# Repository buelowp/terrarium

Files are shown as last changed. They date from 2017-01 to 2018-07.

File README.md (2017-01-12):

# Terrarium Control

The idea here is to provide a mechanism for controlling a small terrarium for plants that like humidity and warm. I'm doing this to control lights for a small planting of venus flytraps in my office. It provides a small bit of fun engineering for a simple mechanism.

## What's needed

1. WeMos D1 Mini (microcontroller)
1. 1.3 in OLED (Adafruit product id 938)
1. DHT22 (Temp and Humidity)
1. Soil Moisture Sensor (Sparkfun SEN-13322)
1. NeoPixel strip (Adafruit product id 1426)
1. UV LED 400nm (Sparkfun COM-08662)
1. 3v3 voltage regulator (Sparkfun COM-00526)
1. Power Supply (Sparkfun TOL-12889)
1. 1 x 470ohm 1/4 watt resistor
1. 2 x 1kohm 1/4 watt resistor
1. 1 x 10kohm 1/4 watt resistor
1. 2 x 2N3904 NPN Transistor (Sparkfun)
1. 1 x 100uf capacitor

## How to build it

The design is based on building a plastic terrarium from PVC and 3d printed parts. The 3d parts are a base and cap. There are 2 caps included, one that fits the OSH Park PCB, and one that would work with a standard breadboard solution. The 3d printed files include the .skp files if you want to make changes. The base contains the peat/soil, and the cap contains the electronics. The visible portion is 4 cut Plexi sheets (1/8 in) to fit the base and cap. These are fashioned into a box onto which the base and cap fit.

More to come.

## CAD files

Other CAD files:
Mech/base.skp
Mech/cap.skp

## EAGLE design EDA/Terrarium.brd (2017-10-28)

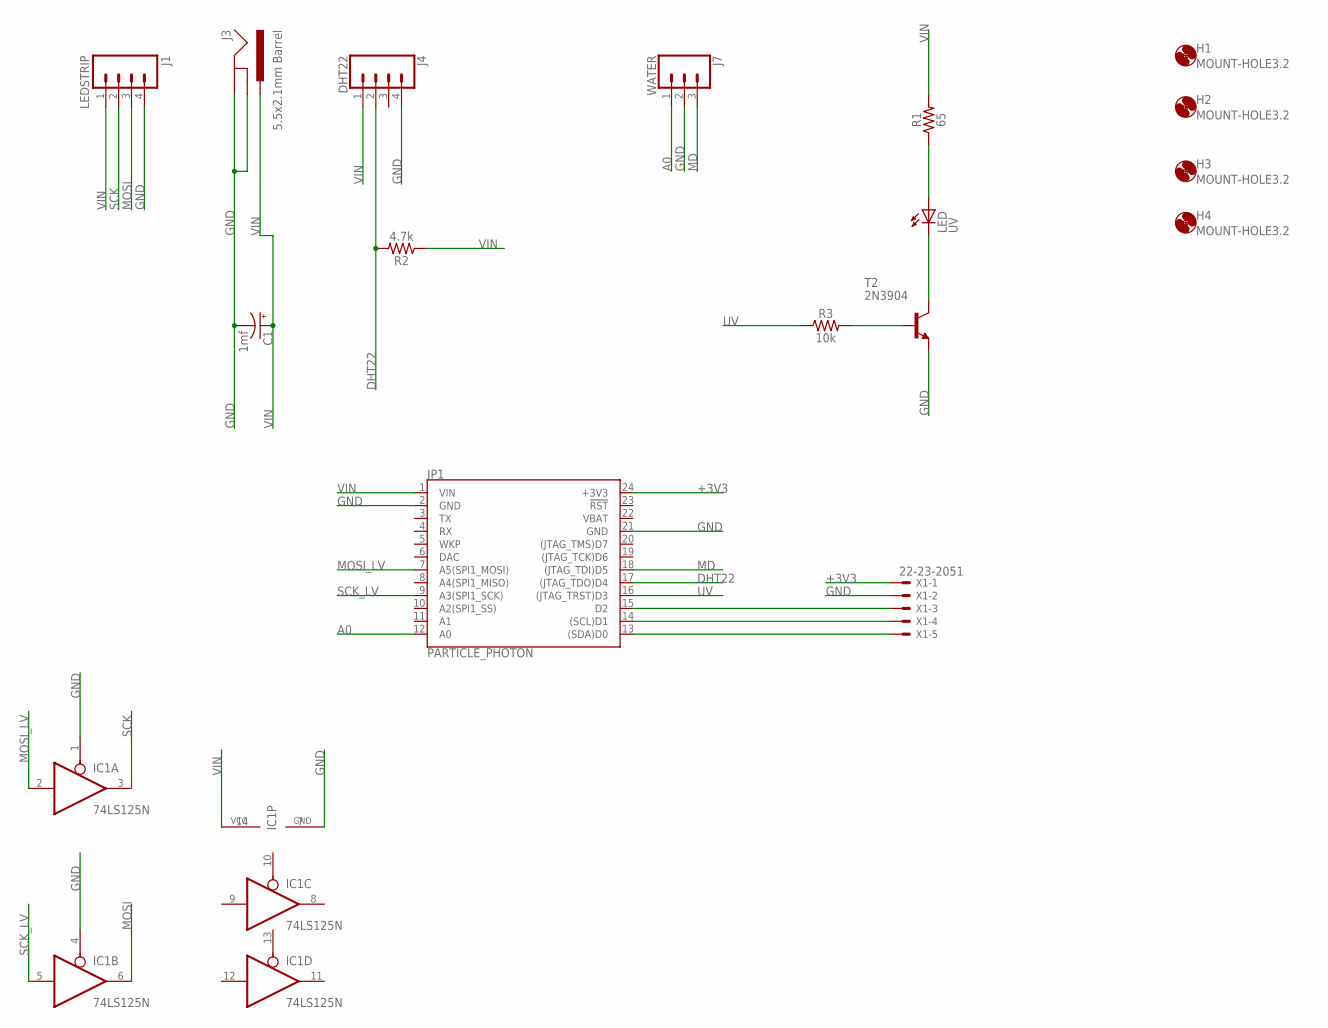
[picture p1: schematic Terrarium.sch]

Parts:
C1: 1mf; CPOL-RADIAL-5MM-10MM-KIT
H1, H2, H3, H4: MOUNT-HOLE3.2; 3,2
IC1: 74LS125N; DIL14
J1: LEDSTRIP; 1X04@1
J3: 5.5x2.1mm Barrel; POWER_JACK_SMD
J4: DHT22; 1X04
J7: WATER; 1X03
JP1: PARTICLE_PHOTON
LED: UV; LED5MM
R1: 65; AXIAL-0.3
R2: 4.7k; AXIAL-0.3
R3: 10k; AXIAL-0.3
T2: 2N3904; TO92
X1: 22-23-2051

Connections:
+3V3: JP1.24 (+3V3), X1.1
A0: J7.1, JP1.12 (A0)
DHT22: J4.2, JP1.17 ((JTAG_TDO)D4), R2.P$2 (2)
GND: C1.-, IC1.1 (OE), IC1.4 (OE), IC1.7 (GND), J1.4, J3.GND (GNDBREAK), J3.P$4 (GND), J4.4, J7.2, JP1.2 (GND), JP1.21 (GND), T2.3 (E), X1.2
MD: J7.3, JP1.18 ((JTAG_TDI)D5)
MOSI: IC1.6 (O), J1.3
MOSI_LV: IC1.2 (I), JP1.7 (A5(SPI1_MOSI))
unnamed: R3.P$2 (2), T2.2 (B)
unnamed: JP1.13 ((SDA)D0), X1.5
unnamed: LED.K (C), T2.1 (C)
unnamed: LED.A, R1.P$1 (1)
unnamed: JP1.14 ((SCL)D1), X1.4
unnamed: JP1.15 (D2), X1.3
SCK: IC1.3 (O), J1.2
SCK_LV: IC1.5 (I), JP1.9 (A3(SPI1_SCK))
UV: JP1.16 ((JTAG_TRST)D3), R3.P$1 (1)
VBAT: JP1.22 (VBAT)
VIN: C1.+, IC1.14 (VCC), J1.1, J3.VIN0 (PWR), J4.1, JP1.1 (VIN), R1.P$2 (2), R2.P$1 (1)

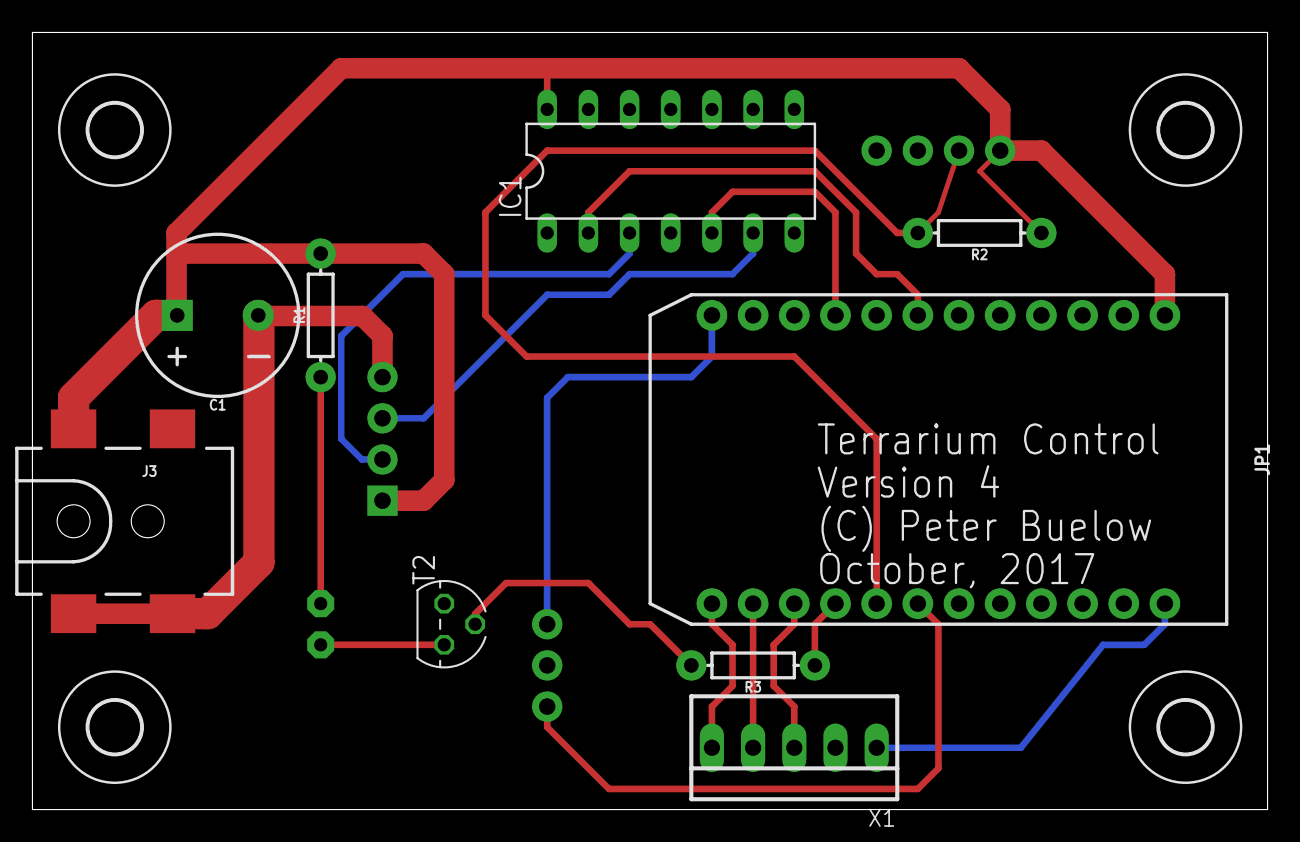
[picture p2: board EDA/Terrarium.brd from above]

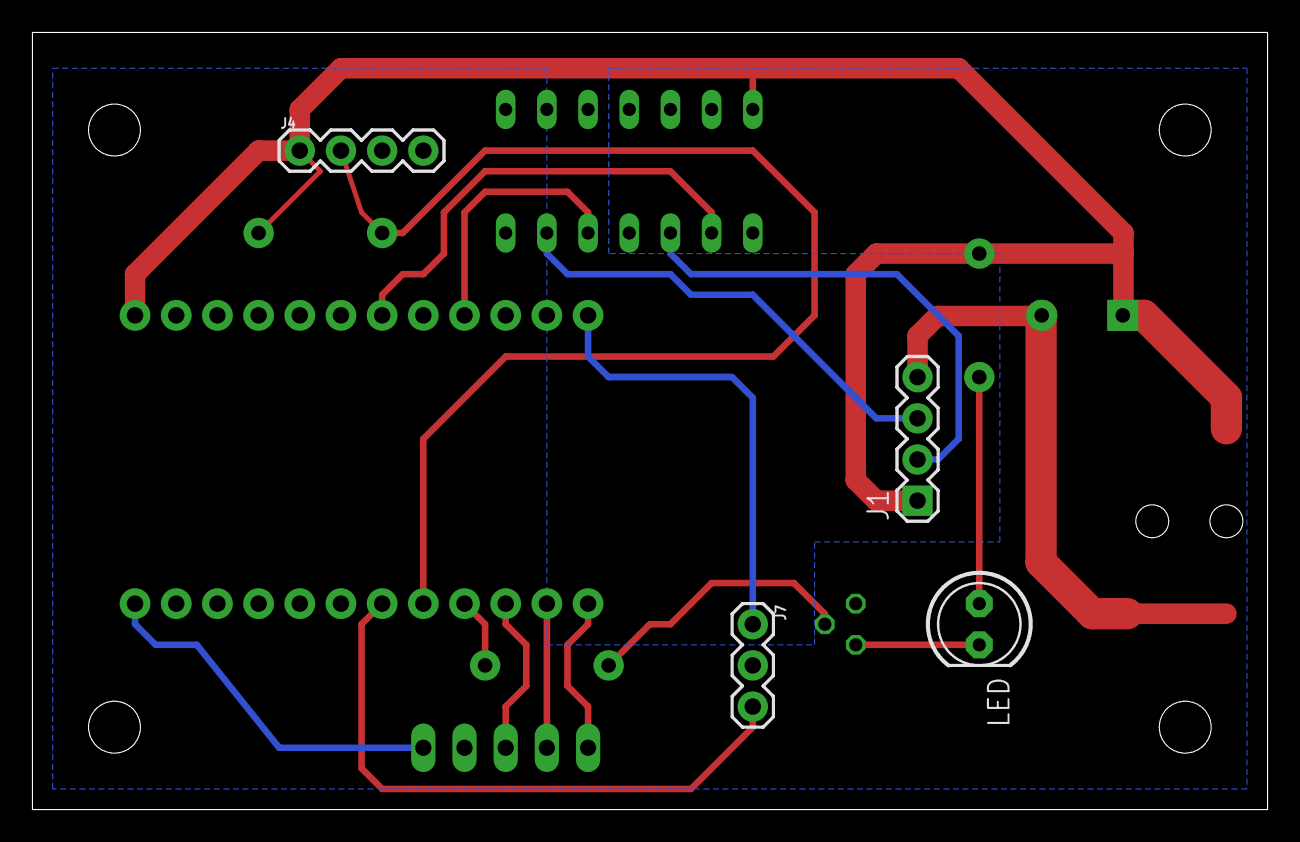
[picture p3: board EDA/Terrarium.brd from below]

Board: 2 copper layers, 76.2 x 47.9 mm, 17 parts (4 on the bottom side), 17 nets.

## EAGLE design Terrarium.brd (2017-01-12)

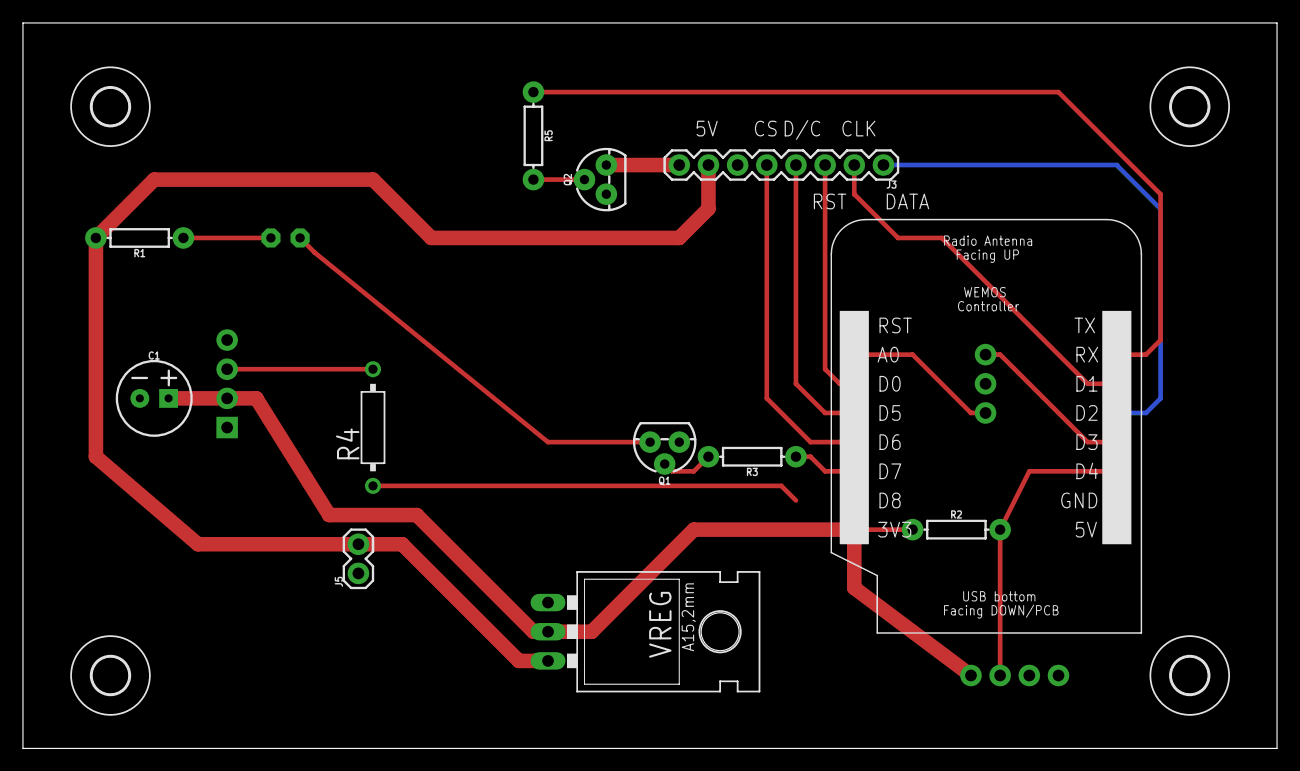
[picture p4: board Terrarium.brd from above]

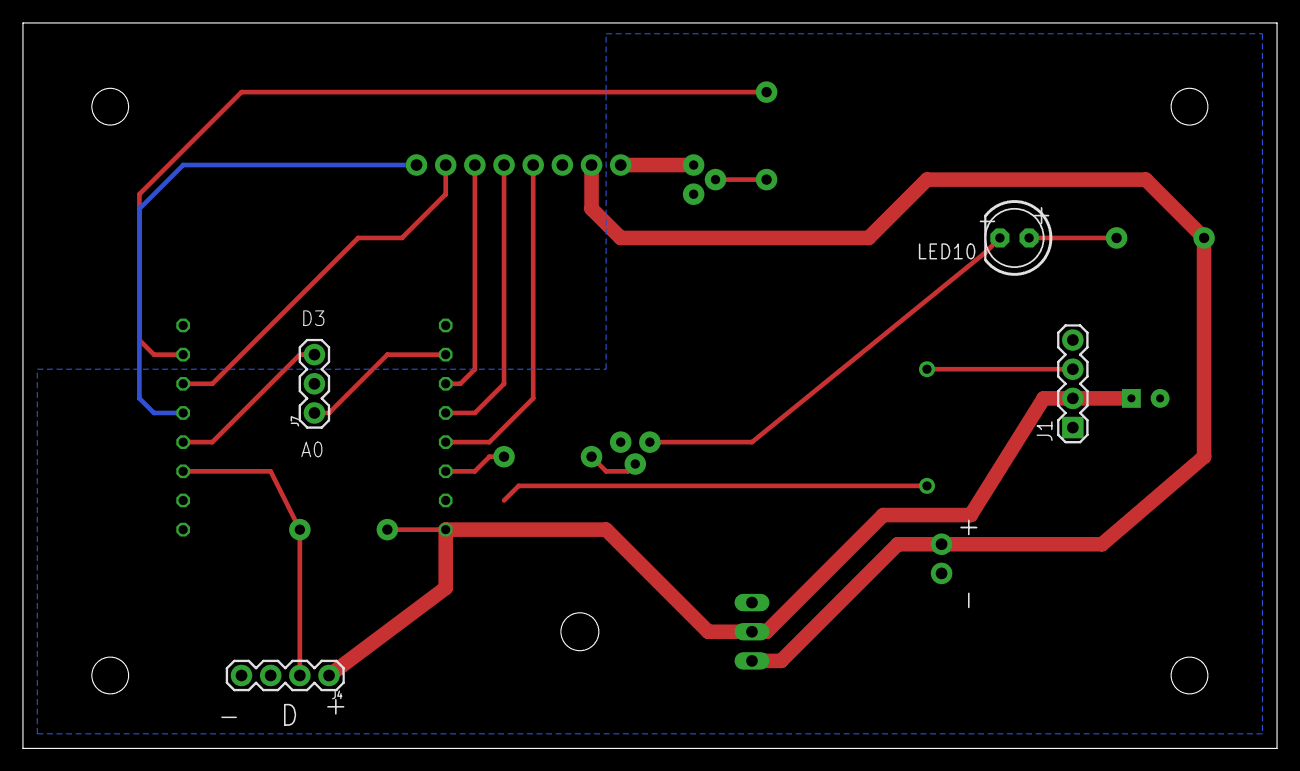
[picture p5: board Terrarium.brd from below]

Board: 2 copper layers, 109.2 x 63.2 mm, 20 parts (4 on the bottom side), 20 nets.

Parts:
C1: 100uF; CPOL-RADIAL-2.5MM-6.5MM
H1, H2, H3, H4: MOUNT-HOLE3.2; 3,2
J1: LEDSTRIP; 1X04@1
J3: OLED; 1X08
J4: DHT22; 1X04
J5: PWR; 1X02
J7: WATER; 1X03
LED10: UV; LED5MM
Q1, Q2: 2N3904; TO-92
R1: 100; AXIAL-0.3
R2: 10k; AXIAL-0.3
R3, R5: 1k; AXIAL-0.3
R4: 470ohm; RS1/4
U$1: WEMOS
VREG: LD1117VXX; 78XXL

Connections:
3V3: C1.1, J1.2, J4.1, R2.P$1, U$1.3V3, VREG.GND
5V: J3.7, J5.2, R1.P$2, VREG.OUT
A0: J7.1, U$1.A0
CS: J3.5, U$1.D6
DC: J3.4, U$1.D5
DHT22: J4.2, R2.P$2, U$1.D4
DINLIGHT: J1.3, R4.2
GND: C1.2, J1.1, J1.4, J4.4, J5.1, J7.2, Q1.1, Q2.1, U$1.GND, VREG.IN
LED_DIN: R4.1, U$1.D8
MD: J7.3, U$1.D3
unnamed: J3.8, Q2.3
unnamed: Q1.2, R3.P$2
unnamed: LED10.K, Q1.3
unnamed: LED10.A, R1.P$1
unnamed: Q2.2, R5.P$2
OLEDPW: R5.P$1, U$1.RX
RST: J3.3, U$1.D0
SCL: J3.2, U$1.D1
SDA: J3.1, U$1.D2
UVPWR: R3.P$1, U$1.D7

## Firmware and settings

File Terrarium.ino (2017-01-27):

/*
MIT License

Copyright (c) 2017 Peter Buelow (goballstate at gmail dot com)

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
THE SOFTWARE IS PROVIDED "AS IS", WITHOUT WARRANTY OF ANY KIND, EXPRESS OR
IMPLIED, INCLUDING BUT NOT LIMITED TO THE WARRANTIES OF MERCHANTABILITY,
FITNESS FOR A PARTICULAR PURPOSE AND NONINFRINGEMENT. IN NO EVENT SHALL THE
AUTHORS OR COPYRIGHT HOLDERS BE LIABLE FOR ANY CLAIM, DAMAGES OR OTHER
LIABILITY, WHETHER IN AN ACTION OF CONTRACT, TORT OR OTHERWISE, ARISING FROM,
OUT OF OR IN CONNECTION WITH THE SOFTWARE OR THE USE OR OTHER DEALINGS IN THE
SOFTWARE.
*/

#include <Time.h>
#include <TimeLib.h>

#include <ESP8266WiFi.h>
#include <ESP8266WiFiAP.h>
#include <ESP8266WiFiGeneric.h>
#include <ESP8266WiFiMulti.h>
#include <ESP8266WiFiScan.h>
#include <ESP8266WiFiSTA.h>
#include <ESP8266WiFiType.h>
#include <WiFiClient.h>
#include <WiFiClientSecure.h>
#include <WiFiServer.h>
#include <WiFiUdp.h>

#include <NtpClientLib.h>
#include <DHT.h>
#include <Adafruit_GFX.h>
#include <gfxfont.h>
#include <Adafruit_SSD1306.h>
#include <FastLED.h>

#include "SunSet.h"

#define UV_LED            D7
#define NUM_LEDS          8
#define DHTTYPE           DHT22
#define ONE_HOUR          (1000*60*60)
#define ONE_MINUTE        (1000*60)
#define CST_OFFSET        -6
#define DST_OFFSET        (CST_OFFSET + 1)
#define TIME_BASE_YEAR    2015

// Arlington Heights, IL, USA
#define LATITUDE          42.058102
#define LONGITUDE         87.984189

// If using software SPI (the default case):
#define OLED_RESET  D0
#define OLED_CLK    D1
#define OLED_MOSI   D2
#define M_DETECT    D8  // Should be D3, testing
#define DHT_22      D4
#define OLED_DC     D5
#define OLED_CS     D6
#define UV_LED      D7
#define LED_DIN     D3  // Should be D8, testing
#define OLED_PW     RX
#define MOIST       A0

Adafruit_SSD1306 display(OLED_MOSI, OLED_CLK, OLED_DC, OLED_RESET, OLED_CS);

CRGB leds[NUM_LEDS];
DHT dht(DHT_22, DHTTYPE);
SunSet sun;
int g_sunposition;

float g_humidity;
float g_temp;
int g_moisture;

const uint8_t _usDSTStart[6] = {8,13,12,11,10, 8};
const uint8_t _usDSTEnd[22]   = {1, 6, 5, 4, 3, 1};

bool isSunrise()
{
  int sunrise_p = ((hour() * 60 + minute()) - (sun.calcSunrise() - 30));

  if (sunrise_p >= 0 && sunrise_p < 60) {
    Serial.print("Sunrise_p is:");
    Serial.println(sunrise_p);
    g_sunposition = sunrise_p * 4;
    return true;
  }

  return false;
}

bool isSunset()
{
  int sunset_p = ((hour() * 60 + minute()) - (sun.calcSunset() - 30));

  if (sunset_p >= 0 && sunset_p < 60) {
    Serial.print("Sunset_p is:");
    Serial.println(sunset_p);
    g_sunposition = (60 - sunset_p) * 4;
    return true;
  }

  return false;
}

bool isDaytime()
{
  bool test = (isSunset() || isSunrise());
  return test;
}

int currentTimeZone()
{
  int offset = CST_OFFSET;

    if (month() > 3 && month() < 11) {
        offset = DST_OFFSET;
    }
    else if (month() == 3) {
        if ((day() == _usDSTStart[year() -  TIME_BASE_YEAR]) && hour() >= 2)
            offset = DST_OFFSET;
        else if (day() > _usDSTStart[year() -  TIME_BASE_YEAR])
            offset = DST_OFFSET;
    }
    else if (month() == 11) {
        if ((day() == _usDSTEnd[year() -  TIME_BASE_YEAR]) && hour() <=2)
            offset = DST_OFFSET;
        else if (day() > _usDSTEnd[year() -  TIME_BASE_YEAR])
            offset = CST_OFFSET;
    }

    String debug(String(__FUNCTION__) + ": Current timezone is " + offset);
    Serial.println(debug);
    return offset;
}

void printDisplay()
{
  display.clearDisplay();
  display.setTextSize(1);
  display.setTextColor(WHITE);
  display.setCursor(0,0);
  display.print("Temperature: ");
  display.print(g_temp, 1);
  display.setCursor(0, 10);
  display.print("Moisture:    ");
  display.print(g_moisture);
  display.setCursor(0, 20);
  display.print("Humidity:    ");
  display.print(g_humidity, 1);
  display.display();
}

void getEnvironmental()
{
  Serial.println("Checking environment");
  g_humidity = dht.readHumidity();
  g_temp = dht.readTemperature(true);
}

void getSoilMoisture()
{
  digitalWrite(M_DETECT, HIGH);
  delay(10);
  g_moisture = analogRead(MOIST);
  digitalWrite(M_DETECT, LOW);
}

void switchUV(bool s)
{
  if (s)
    digitalWrite(UV_LED, HIGH);
  else
    digitalWrite(UV_LED, LOW);
}

void setup() 
{
  Serial.begin(115200);

  g_sunposition = 0;
  
  pinMode(UV_LED, OUTPUT);                // Setup the UV LED
  pinMode(M_DETECT, OUTPUT);              // Setup the On/Off for the soil moisture sensor
  pinMode(OLED_PW, OUTPUT);               // Make the RX line a normal 3v3 GPIO
  pinMode(DHT_22, INPUT);                 // Setup the 1-wire Temp and humidity

  digitalWrite(UV_LED, HIGH);
  
  FastLED.addLeds<NEOPIXEL, LED_DIN>(leds, NUM_LEDS);
  dht.begin();

  // by default, we'll generate the high voltage from the 3.3v line internally! (neat!)
  display.begin(SSD1306_SWITCHCAPVCC);
  display.clearDisplay();
  display.setTextSize(1);
  display.setTextColor(WHITE);
  display.setCursor(0,5);
  display.println("Terrorarium");
  display.display();

  WiFi.persistent(false);
  WiFi.begin("LivingRoom", "Motorazr2V8");
  while (WiFi.status() != WL_CONNECTED) {
    delay(500);
    Serial.print(".");
  }
  Serial.println("WiFi connected");
  Serial.print("IP address: ");
  Serial.println(WiFi.localIP());

  NTP.onNTPSyncEvent([](NTPSyncEvent_t error) {
    if (error) {
    Serial.print("Time Sync error: ");
    if (error == noResponse)
      Serial.println("NTP server not reachable");
    else if (error == invalidAddress)
      Serial.println("Invalid NTP server address");
    }
    else {
      Serial.print("Got NTP time: ");
      Serial.println(NTP.getTimeDateString(NTP.getLastNTPSync()));
      sun.setCurrentDate(year(), month(), day());
      NTP.setTimeZone(currentTimeZone());
    }
  });
  NTP.begin("pool.ntp.org", 1, true);
  NTP.setInterval(3600);
  NTP.setTimeZone(currentTimeZone());

  sun.setPosition(LATITUDE, LONGITUDE, currentTimeZone());
  delay(5000);
  getSoilMoisture();
  getEnvironmental();
}

void loop() 
{
  int sunrise;
  int sunset;
  
  EVERY_N_MILLISECONDS(ONE_HOUR)
  {
    sun.setTZOffset(currentTimeZone());
    getSoilMoisture();
  }

  EVERY_N_MILLISECONDS(ONE_MINUTE)
  {
    getEnvironmental();
  }

  // Update the display
  printDisplay();
  
  if (isSunrise()) {
    for (int i = 0; i < NUM_LEDS; i++) {
      leds[i].r = g_sunposition;
      leds[i].b = g_sunposition;
      leds[i].g = (g_sunposition / 2);
    }
    FastLED.show();
  }
  else if (isDaytime()) {
    for (int i = 0; i < NUM_LEDS; i++) {
      leds[i].r = 250;
      leds[i].b = 250;
      leds[i].g = 125;
    }
    FastLED.show();
  }
  else if (isSunset()) {
    for (int i = 0; i < NUM_LEDS; i++) {
      leds[i].r = g_sunposition;
      leds[i].b = g_sunposition;
      leds[i].g = (g_sunposition / 2);
    }
    FastLED.show();    
  }
  else {
    for (int i = 0; i < NUM_LEDS; i++) {
      leds[i] = CRGB::Black;
    }
    FastLED.show();
    g_sunposition = 0;
  }
  
  if (hour() > 9 && hour() < 15)
    switchUV(true);
  else
    switchUV(false);
    
  delay(1000);
}

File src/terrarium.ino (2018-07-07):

/*
MIT License

Copyright (c) 2017 Peter Buelow (goballstate at gmail dot com)

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
THE SOFTWARE IS PROVIDED "AS IS", WITHOUT WARRANTY OF ANY KIND, EXPRESS OR
IMPLIED, INCLUDING BUT NOT LIMITED TO THE WARRANTIES OF MERCHANTABILITY,
FITNESS FOR A PARTICULAR PURPOSE AND NONINFRINGEMENT. IN NO EVENT SHALL THE
AUTHORS OR COPYRIGHT HOLDERS BE LIABLE FOR ANY CLAIM, DAMAGES OR OTHER
LIABILITY, WHETHER IN AN ACTION OF CONTRACT, TORT OR OTHERWISE, ARISING FROM,
OUT OF OR IN CONNECTION WITH THE SOFTWARE OR THE USE OR OTHER DEALINGS IN THE
SOFTWARE.
*/
#include <Adafruit_SSD1306.h>
#include <Adafruit_DHT.h>
#include <FastLED.h>
#include "SunSet.h"

FASTLED_USING_NAMESPACE;

#define NUM_LEDS          8
#define DHTTYPE           DHT22
#define SEVEN_HOURS       (60*60*7)
#define SIX_HOURS         (1000*60*60*6)
#define ONE_HOUR          (1000*60*60)
#define ONE_MINUTE        (1000*60)
#define CST_OFFSET        -6
#define DST_OFFSET        (CST_OFFSET + 1)
#define TIME_BASE_YEAR    2015

// Arlington Heights, IL, USA
#define LATITUDE          42.058102
#define LONGITUDE         87.984189

// If using software SPI (the default case):
#define OLED_RESET  D2
//#define OLED_SCL    D1
//#define OLED_SDA    D0
#define MD          D4
#define MOIST       A0
#define DHTPIN      D3
//#define OLED_DC     D2
//#define OLED_CS     D4
#define UV_LED      D5
#define LED_DIN     D6

int g_mins;
int g_sunrise;
int g_sunset;
int g_timeZone;
int g_brightVal;

Adafruit_SSD1306 display = Adafruit_SSD1306(OLED_RESET);

DHT dht(DHTPIN, DHTTYPE);
CRGB leds[NUM_LEDS];
SunSet sun;
int g_sunposition;
unsigned int DHTnextSampleTime;	    // Next time we want to start sample
bool bDHTstarted;		    // flag to indicate we started acquisition

float g_humidity;
float g_temp;
int g_moisture;

const uint8_t _usDSTStart[6] = {8,13,12,11,10, 8};
const uint8_t _usDSTEnd[6]   = {1, 6, 5, 4, 3, 1};

int sunrise()
{
  if (g_mins >= (sun.calcSunrise() - 30) && g_mins < (sun.calcSunrise() + 30)) {
    return (g_mins - (sun.calcSunrise() - 30)) * 4;
  }
  return -1;
}

int sunset()
{
  if (g_mins >= (sun.calcSunset() - 30) && g_mins < (sun.calcSunset() + 30)) {
    return ((sun.calcSunset() + 30) - g_mins) * 4;
  }
  return -1;
}

bool isDaytime()
{
  if ((g_mins >= (sun.calcSunrise() + 30)) && (g_mins < (sun.calcSunset() - 30)))
    return true;

  return false;
}

int currentTimeZone()
{
  int offset = CST_OFFSET;

    if (Time.month() > 3 && Time.month() < 11) {
        offset = DST_OFFSET;
    }
    else if (Time.month() == 3) {
        if ((Time.day() == _usDSTStart[Time.year() -  TIME_BASE_YEAR]) && Time.hour() >= 2)
            offset = DST_OFFSET;
        else if (Time.day() > _usDSTStart[Time.year() -  TIME_BASE_YEAR])
            offset = DST_OFFSET;
    }
    else if (Time.month() == 11) {
        if ((Time.day() == _usDSTEnd[Time.year() -  TIME_BASE_YEAR]) && Time.hour() <=2)
            offset = DST_OFFSET;
        else if (Time.day() > _usDSTEnd[Time.year() -  TIME_BASE_YEAR])
            offset = CST_OFFSET;
    }

    String debug(String(__FUNCTION__) + ": Current timezone is " + offset);
    Serial.println(debug);
    return offset;
}

void printDisplay()
{
  display.clearDisplay();
  display.setTextSize(1);
  display.setTextColor(WHITE);
  display.setCursor(0,0);
  display.print("Temperature: ");
  display.print(g_temp, 1);
  display.setCursor(0, 15);
  display.print("Moisture:    ");
  display.print(g_moisture);
  display.setCursor(0, 30);
  display.print("Humidity:    ");
  display.print(g_humidity, 1);
  display.display();
}

void getEnvironmental()
{
  Serial.println("Checking environment");
  g_humidity = dht.getHumidity();
  g_temp = dht.getTempFarenheit();
}

void getSoilMoisture()
{
  digitalWrite(MD, HIGH);
  delay(10);
  g_moisture = analogRead(MOIST);
  digitalWrite(MD, LOW);
}

void switchUV(bool s)
{
  if (s)
    digitalWrite(UV_LED, HIGH);
  else
    digitalWrite(UV_LED, LOW);
}

void setup()
{
  Serial.begin(115200);

  g_sunposition = 0;
  g_brightVal = 0;

  pinMode(UV_LED, OUTPUT);                // Setup the UV LED
  pinMode(MD, OUTPUT);              // Setup the On/Off for the soil moisture sensor

  digitalWrite(UV_LED, HIGH);
  digitalWrite(MD, LOW);

  FastLED.addLeds<APA102>(leds, NUM_LEDS);

  Particle.variable("g_mins", g_mins);
  Particle.variable("g_sunrise", g_sunrise);
  Particle.variable("g_sunset", g_sunset);
  Particle.variable("g_timeZone", g_timeZone);
  Particle.variable("g_brightVal", g_brightVal);

  // by default, we'll generate the high voltage from the 3.3v line internally! (neat!)
  display.begin(SSD1306_SWITCHCAPVCC, 0x3D);
  display.clearDisplay();
  display.setTextSize(1);
  display.setTextColor(WHITE);
  display.setCursor(0,5);
  display.println("Terrarium");
  display.display();

  DHTnextSampleTime = 0;  // Start the first sample immediately

  Time.zone(currentTimeZone());
  sun.setPosition(LATITUDE, LONGITUDE, currentTimeZone());
  sun.setCurrentDate(Time.year(), Time.month(), Time.day());
  dht.begin();
  delay(5000);
  getSoilMoisture();
  getEnvironmental();
}

void loop()
{
  g_sunrise = sun.calcSunrise();
  g_sunset = sun.calcSunset();
  g_mins = Time.hour() * 60 + Time.minute();
  g_timeZone = currentTimeZone();

  EVERY_N_MILLISECONDS(SIX_HOURS)
  {
    Particle.syncTime();
  }

  EVERY_N_MILLISECONDS(ONE_HOUR)
  {
    sun.setCurrentDate(Time.year(), Time.month(), Time.day());
    Time.zone(currentTimeZone());
    sun.setTZOffset(currentTimeZone());
    getSoilMoisture();
  }

  EVERY_N_MILLISECONDS(ONE_MINUTE)
  {
    getEnvironmental();
  }

  // Update the display
  printDisplay();

  if ((g_brightVal = sunrise()) != -1) {
    for (int i = 0; i < NUM_LEDS; i++) {
      leds[i] = CRGB::White;
    }
    FastLED.setBrightness(g_brightVal);
    FastLED.show();
  }
  else if (isDaytime()) {
    for (int i = 0; i < NUM_LEDS; i++) {
      leds[i] = CRGB::White;
    }
    FastLED.setBrightness(250);
    FastLED.show();
  }
  else if ((g_brightVal = sunset()) != -1) {
    for (int i = 0; i < NUM_LEDS; i++) {
      leds[i] = CRGB::White;
    }
    FastLED.setBrightness(g_brightVal);
    FastLED.show();
  }
  else {
    for (int i = 0; i < NUM_LEDS; i++) {
      leds[i] = CRGB::Black;
    }
    FastLED.show();
  }

  if (Time.hour() >= 8 && Time.hour() <= 16)
    switchUV(true);
  else
    switchUV(false);

  if (Time.hour() >= 20) {
    display.clearDisplay();
    display.display();
    delay(100);
    System.sleep(SLEEP_MODE_DEEP, SEVEN_HOURS);
  }

  delay(1000);
}

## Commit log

2017-01-12 Lots of changes
    Added the Eagle files
    Updated to use PIN names instead of the Wemos pin designations
    Updated logic for turning the lights on and off at sunrise/sunset
    Added sunrise and sunset calculation
    Code cleanup and bugfixes
    [Terrarium.brd, Terrarium.sch]
2017-01-12 Adding the sketchup files for the base and cap
    [base.skp, cap.skp]
2017-01-12 Adding STL files for the cap and base. Updated the cap and base to latest
    [base.skp, base.stl, cap.skp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]
2017-01-15 Some build fixes. Pins will change though as I update the pcb though.
    [Terrarium.ino]
2017-01-26 Fixed a sunrise/sunset bug
    [Terrarium.ino]
2017-01-27 Checkpoint. Still doesn't work exactly right.
    [Terrarium.ino]
2017-01-27 Fixed the sunrise/sunset bug
    [Terrarium.ino]
2017-10-28 Lots of Photon fix ups
    1. Added correct i2c handling for OLED
    2. Changed pins to match new layout
    3. Starting changes for light bar
    [base.skp, base.stl, cap.skp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]
2017-10-28 Continuing improvements
    1. Update Eagle files for new layout
    2. Update text placement on OLED
    [Terrarium.brd, Terrarium.sch]
2017-10-29 Fixes and some debug variables
    [terrarium.ino]
2017-10-29 Ask the Photon to sync time every hour to avoid drift.
    [terrarium.ino]
2017-10-29 Fixed a calculation bug with sunrise
    [terrarium.ino]

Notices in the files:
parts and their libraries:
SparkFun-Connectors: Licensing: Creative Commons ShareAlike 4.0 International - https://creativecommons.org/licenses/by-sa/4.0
